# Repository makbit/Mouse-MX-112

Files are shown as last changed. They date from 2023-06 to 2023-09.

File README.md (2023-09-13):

# Mouse MX-112 - Free computer mouse with USB and PS/2 interfaces

This is a computer mouse with USB and PS/2 intefaces. There are 3 buttons and a wheel. The PCB is designed to be placed in a cheap plastic case manufactured in china. I have used the plastic case and lenses from the RX-112 mouse as a donor.

The mouse is compatible with Windows and Linux OS.

The device is based on a Silabs 8-bit MCU [EFM8UB20F32](https://www.silabs.com/mcu/8-bit/efm8-universal-bee/device.efm8ub20f32g-qfp32). This MCU has a Fullspeed USB controller and adjustable internal oscillator.

### Advantages of this mouse:
* Open hardware and software design;
* Compliant to hardware and software specification;
* Popular optical sensor ADNS-5050 with 1000+cpi and 8g;
* All electronic components are available in your local shop;
* I use it myself.

The [`Hardware`](Hardware) folder contains Eagle CAD 9 schematics files. The board schematics can be found in the[`Hardware/Mouse-112-sh.png`](Hardware/Mouse-112-sh.png) file.

The firmware is under development...

##### Some pictures of this Mouse MX-112:cool:
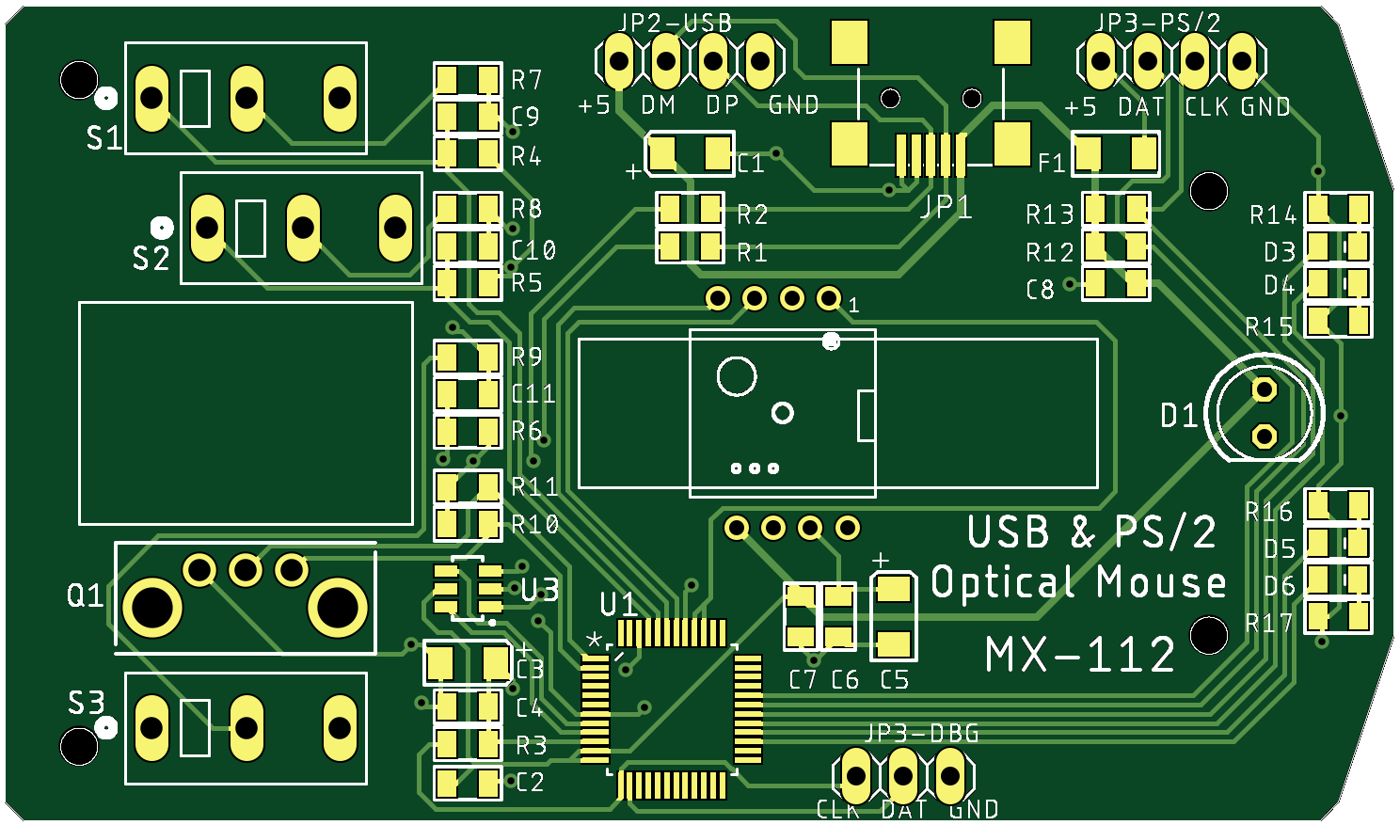
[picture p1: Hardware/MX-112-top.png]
'PCB image'


### Project Info






### TODO :pen:
 - [X] Solder;
 - [X] Test hardware;
 - [ ] Write firmware;
 - [ ] Test firmware;
 - [ ] Find a sponsor :smile:

[GitHub readme tips&tricks](https://help.github.com/articles/basic-writing-and-formatting-syntax/)

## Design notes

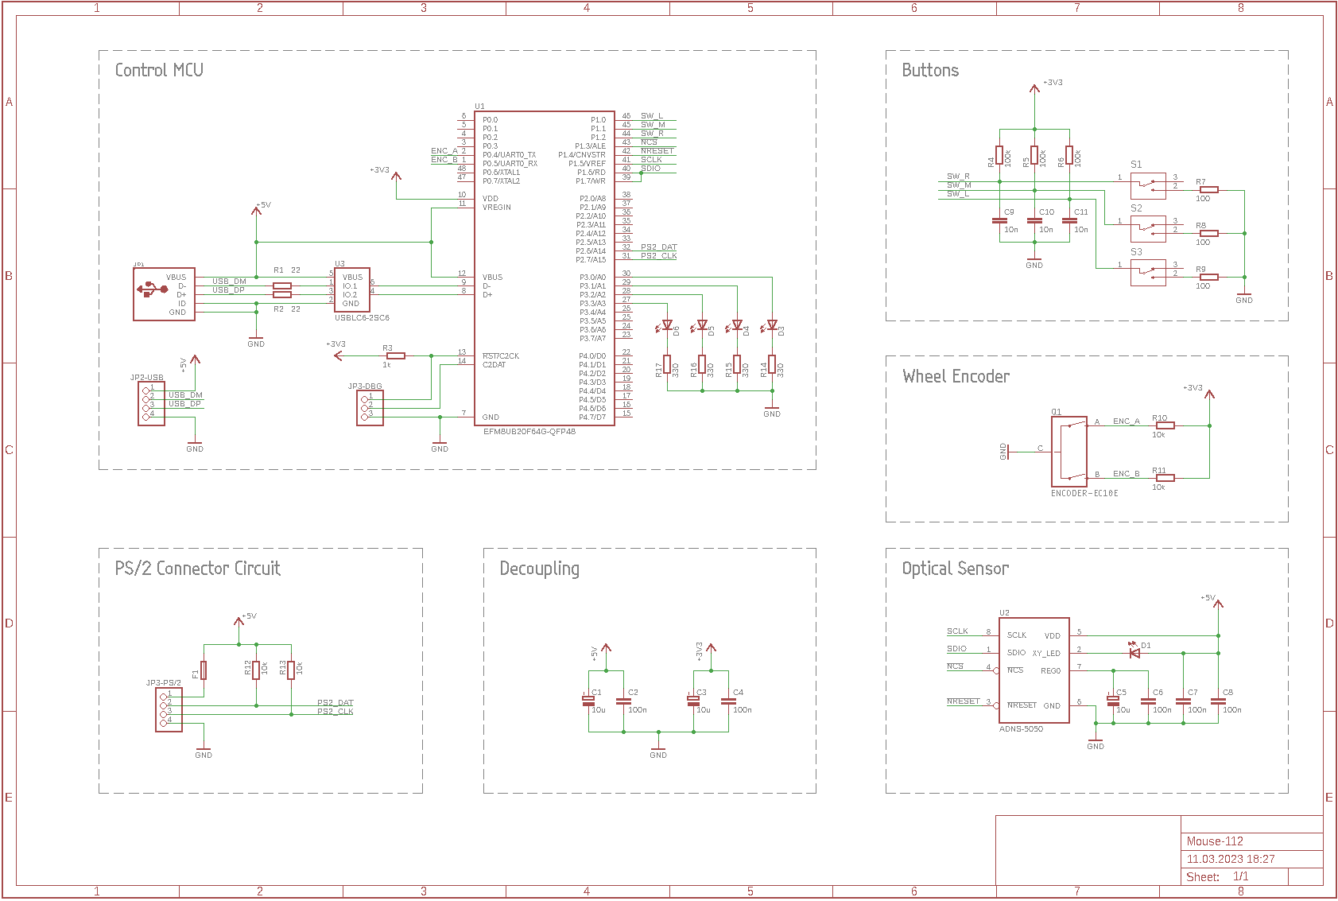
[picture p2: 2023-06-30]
Hardware/Mouse-112-sh.png

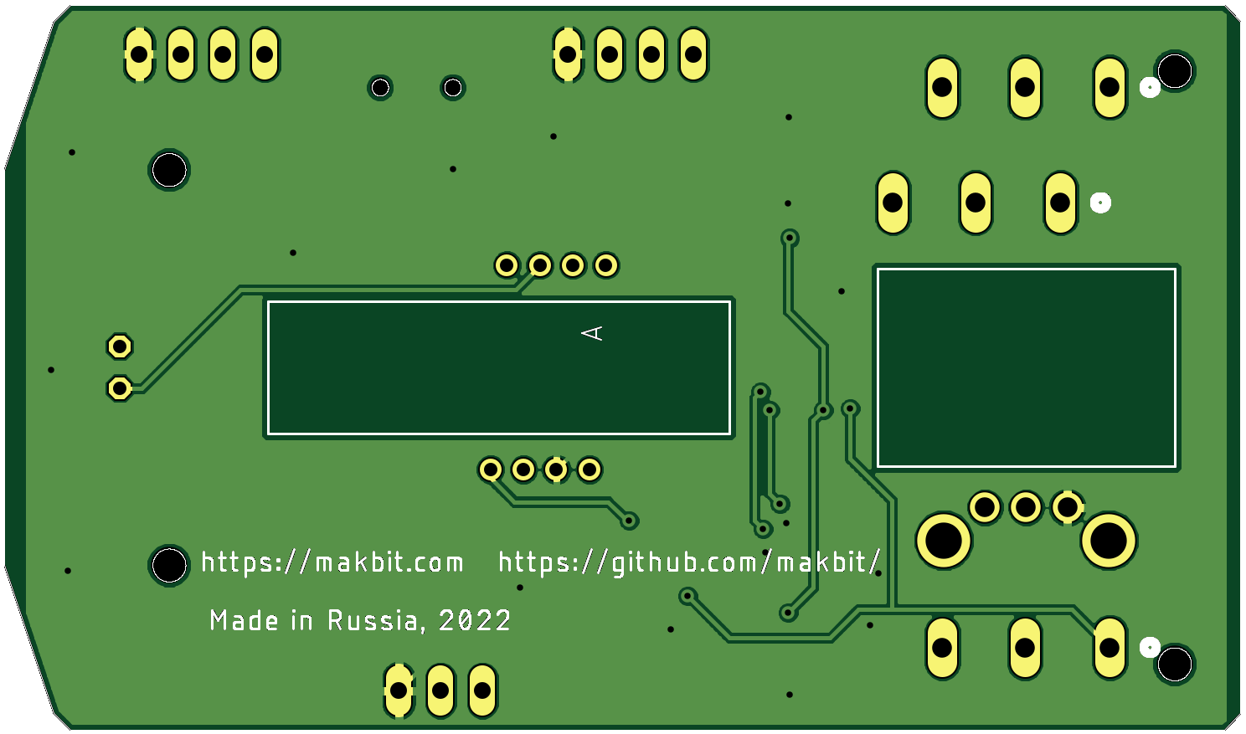
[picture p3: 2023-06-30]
Hardware/MX-112-bottom.png

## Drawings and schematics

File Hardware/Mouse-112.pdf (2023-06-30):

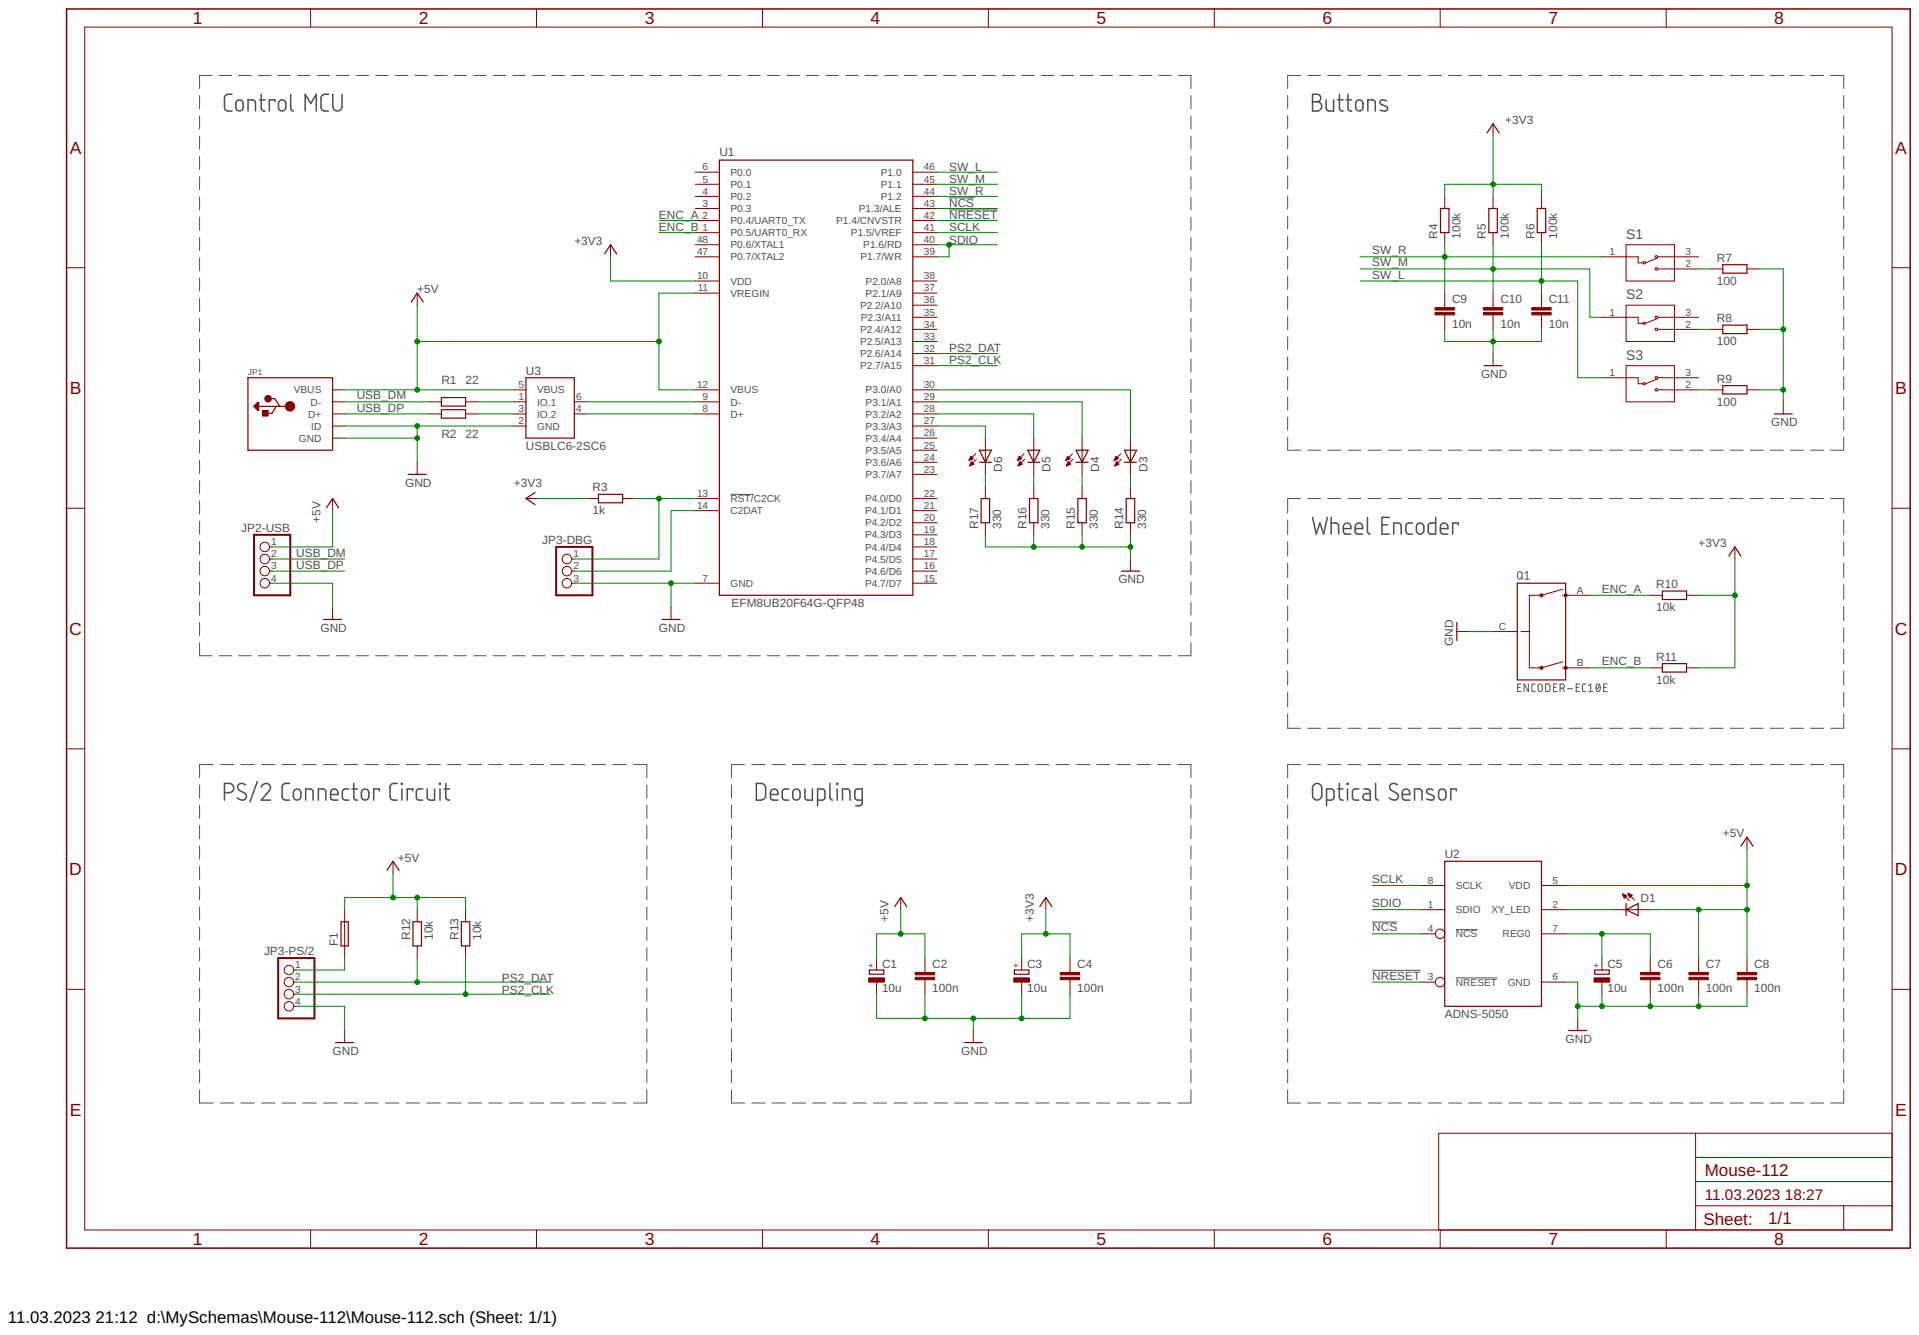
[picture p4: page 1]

11.03.2023 21:12 d:\MySchemas\Mouse-112\Mouse-112.sch (Sheet: 1/1)

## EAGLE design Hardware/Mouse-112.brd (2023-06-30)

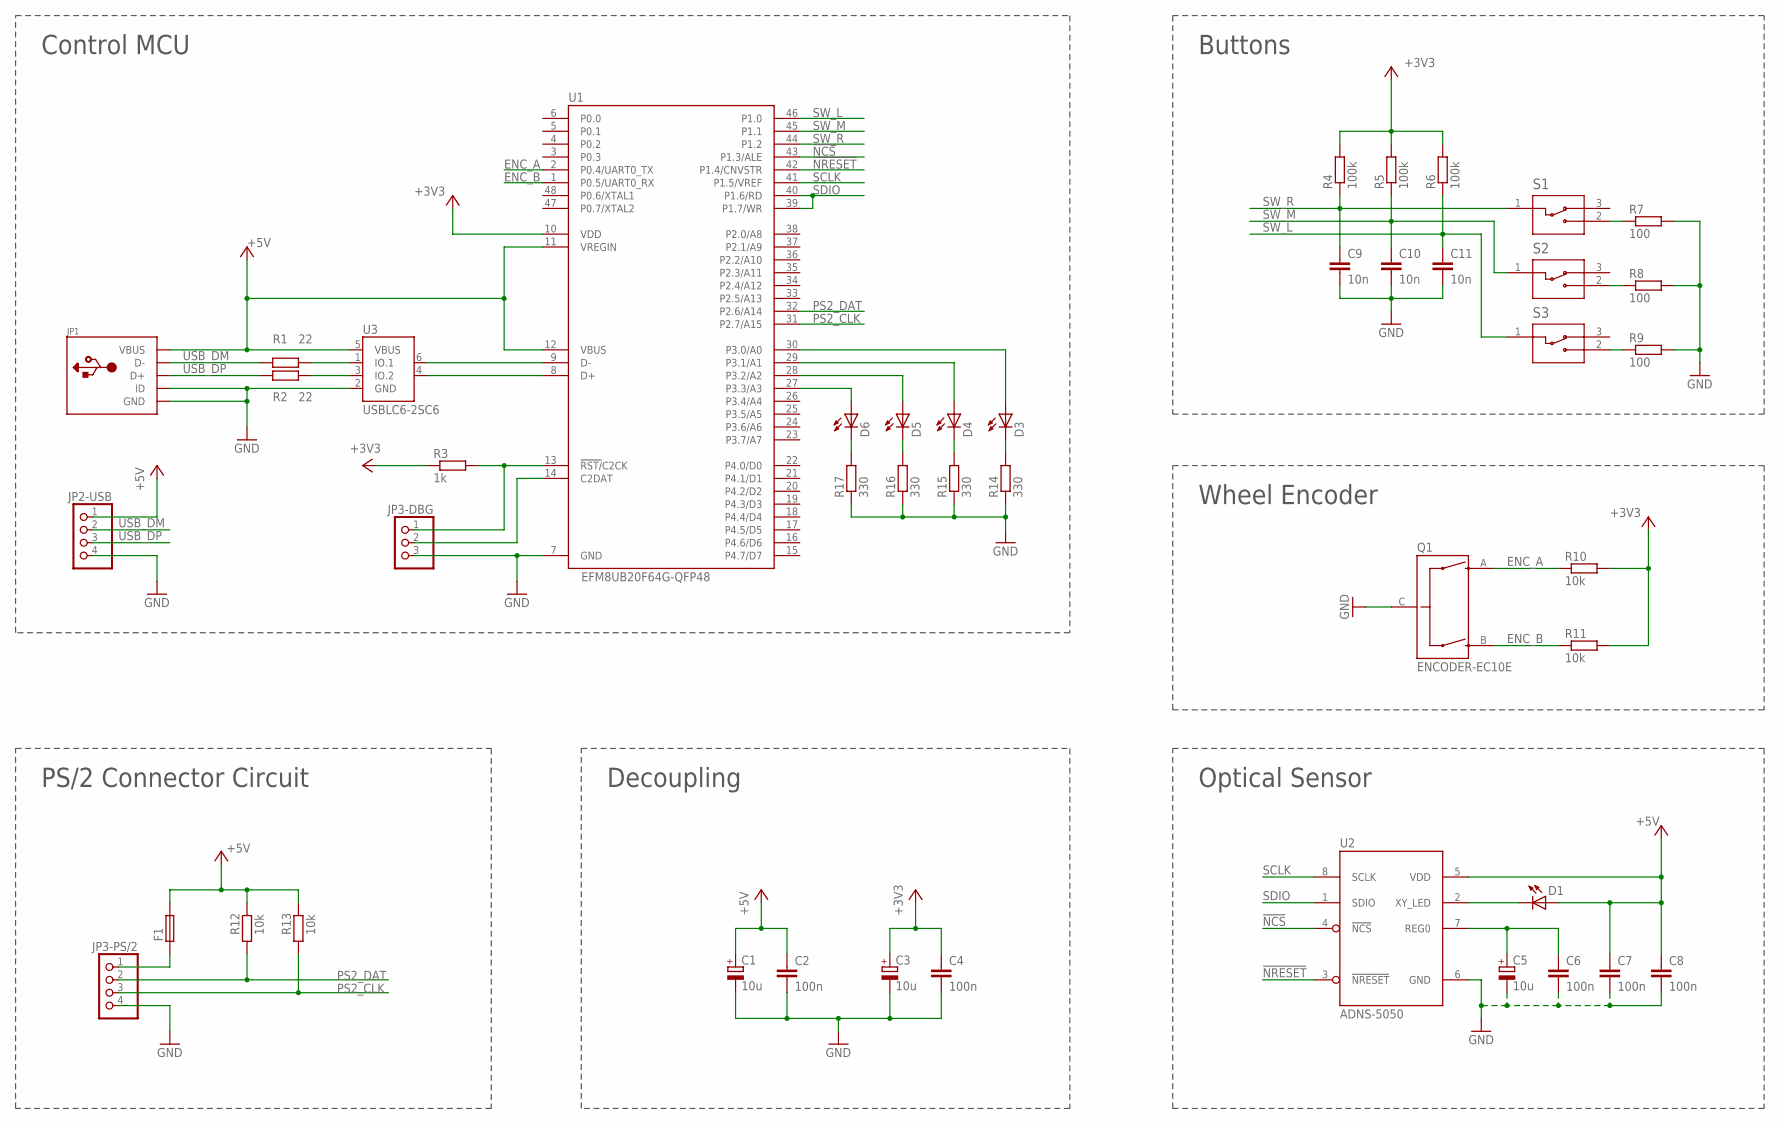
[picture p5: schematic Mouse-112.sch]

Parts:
C1, C3, C5: 10u; RCL-1206F-POL
C2, C4, C6, C7, C8: 100n; RCL-0805F
C9, C10, C11: 10n; RCL-0805F
D1: LED5MM
D3, D4, D5, D6: LEDLED-0805F; LED-0805F
F1: FUSE-NSMF; RCL-1206F
JP1: USB-MINI; USB-MINIB
JP2-USB, JP3-PS/2: PINHD-1X4; 1X04
JP3-DBG: PINHD-1X3; 1X03
Q1: ENCODER-EC10E; ENCODER-10MM
R1, R2: 22; RCL-0805F
R3: 1k; RCL-0805F
R4, R5, R6: 100k; RCL-0805F
R7, R8, R9: 100; RCL-0805F
R10, R11, R12, R13: 10k; RCL-0805F
R14, R15, R16, R17: 330; RCL-0805F
S1, S2, S3: SWITCH-D2F-01; SWITCH-D2F-01L-12.8X5.8MM
U1: EFM8UB20F64G-QFP48; QFP48-7X7-0P5MM
U2: ADNS-5050; ADNS-5050-DIP-8
U3: USBLC6-2SC6; SOT-23-6L

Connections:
!NCS: U1.43 (P1.3/ALE), U2.4 (!NCS)
!NRESET: U1.42 (P1.4/CNVSTR), U2.3 (!NRESET)
+3V3: C3.+, C4.1, R3.1, R4.2, R5.2, R6.2, R10.2, R11.2, U1.10 (VDD)
+5V: C1.+, C2.1, C7.1, C8.1, D1.A, F1.2, JP1.VBUS, JP2-USB.1, R12.2, R13.2, U1.11 (VREGIN), U1.12 (VBUS), U2.5 (VDD), U3.5 (VBUS)
C2CK: JP3-DBG.1, R3.2, U1.13 (!RST/!C2CK)
C2DAT: JP3-DBG.2, U1.14 (C2DAT)
ENC_A: Q1.A, R10.1, U1.2 (P0.4/UART0_TX)
ENC_B: Q1.B, R11.1, U1.1 (P0.5/UART0_RX)
GND: C1.-, C2.2, C3.-, C4.2, C5.-, C6.2, C7.2, C8.2, C9.2, C10.2, C11.2, JP1.GND, JP1.ID, JP2-USB.4, JP3-DBG.3, JP3-PS/2.4, Q1.C, R7.2, R8.2, R9.2, R14.1, R15.1, R16.1, R17.1, U1.7 (GND), U2.6 (GND), U3.2 (GND)
unnamed: D1.K (C), U2.2 (XY_LED)
unnamed: D4.A, U1.29 (P3.1/A1)
unnamed: R2.2, U3.3 (IO.2)
unnamed: R1.2, U3.1 (IO.1)
unnamed: D3.A, U1.30 (P3.0/A0)
unnamed: D4.C, R15.2
unnamed: U1.9 (D-), U3.6 (IO_1)
unnamed: U1.8 (D+), U3.4 (IO_2)
unnamed: D3.C, R14.2
unnamed: F1.1, JP3-PS/2.1
unnamed: D5.C, R16.2
unnamed: R7.1, S1.2
unnamed: R8.1, S2.2
unnamed: R9.1, S3.2
unnamed: D5.A, U1.28 (P3.2/A2)
unnamed: D6.A, U1.27 (P3.3/A3)
unnamed: D6.C, R17.2
PS2_CLK: JP3-PS/2.3, R13.1, U1.31 (P2.7/A15)
PS2_DAT: JP3-PS/2.2, R12.1, U1.32 (P2.6/A14)
REG0: C5.+, C6.1, U2.7 (REG0)
SCLK: U1.41 (P1.5/VREF), U2.8 (SCLK)
SDIO: U1.39 (P1.7/WR), U1.40 (P1.6/RD), U2.1 (SDIO)
SW_L: C11.1, R6.1, S3.1, U1.46 (P1.0)
SW_M: C10.1, R5.1, S2.1, U1.45 (P1.1)
SW_R: C9.1, R4.1, S1.1, U1.44 (P1.2)
USB_DM: JP1.D-, JP2-USB.2, R1.1
USB_DP: JP1.D+, JP2-USB.3, R2.1

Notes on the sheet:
Wheel Encoder
Buttons
Optical Sensor
Control MCU
Decoupling
PS/2 Connector Circuit

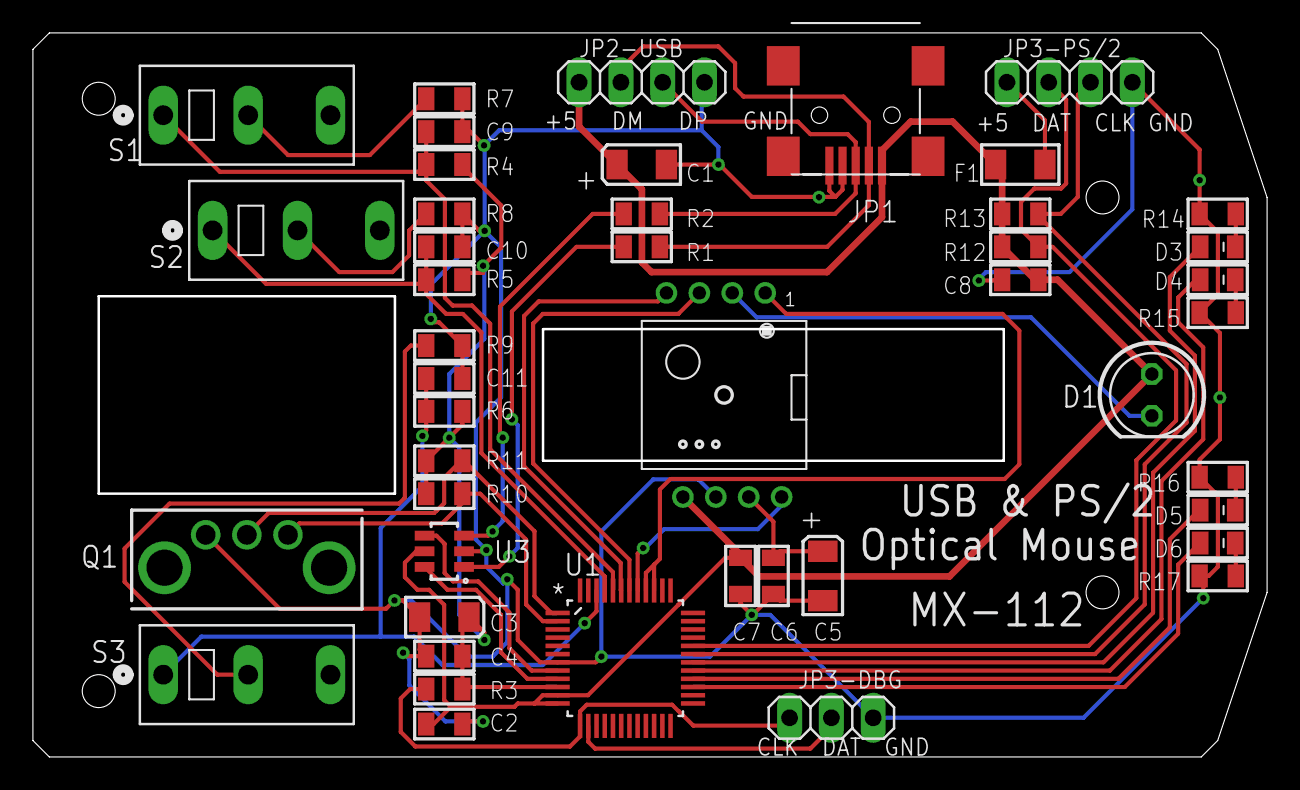
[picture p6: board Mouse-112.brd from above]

Board: 2 copper layers, 75.0 x 44.0 mm, 45 parts (0 on the bottom side), 36 nets.
